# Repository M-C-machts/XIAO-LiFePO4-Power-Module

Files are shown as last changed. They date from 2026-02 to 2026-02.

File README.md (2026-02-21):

# XIAO LiFePO4 Module (Charging + 3.3V Regulator)

Small power-management PCB for running an ESP32 (or other 3.3V devices) from a single **LiFePO4** cell.

This board provides:
- **LiFePO4 charging** from ~5V input
- Proper handling of **charge + discharge**
- A **stable 3.3V output**
- **Battery voltage sense** output via a resistor divider (for ADC monitoring)

## Form factor / compatibility

This module matches the **Seeed Studio XIAO** form factor (approx. 21 x 17.5 mm) and is intended to be:
- soldered directly onto a **Seeed Studio XIAO ESP32C3** (castellated-module style), or
- used as a small **daughter board** on a larger PCB.

## Connections

- **Battery**: JST SH connector (LiFePO4 cell)
- **Charge input**: ~5V
- **Output**: regulated 3.3V
- **VBAT_SENSE**: divided battery-voltage output (connect to an ADC pin)

> Pin names / exact pinout depends on the PCB revision. See the schematic/PCB files in this repo.

## Typical use cases

- Battery-powered ESP32 sensor nodes
- Small portable projects using XIAO-sized MCUs
- Projects needing safe LiFePO4 charging + regulated 3.3V

## Notes / safety

- Use only **single-cell LiFePO4** batteries.
- Verify polarity before connecting the battery.
- Charging from ~5V assumes a suitable 5V source (USB, regulated supply, etc.).

## Repo contents

- KiCad project files (schematic + PCB)
- Manufacturing outputs - todo
- BOM / assembly notes - todo

## License

todo

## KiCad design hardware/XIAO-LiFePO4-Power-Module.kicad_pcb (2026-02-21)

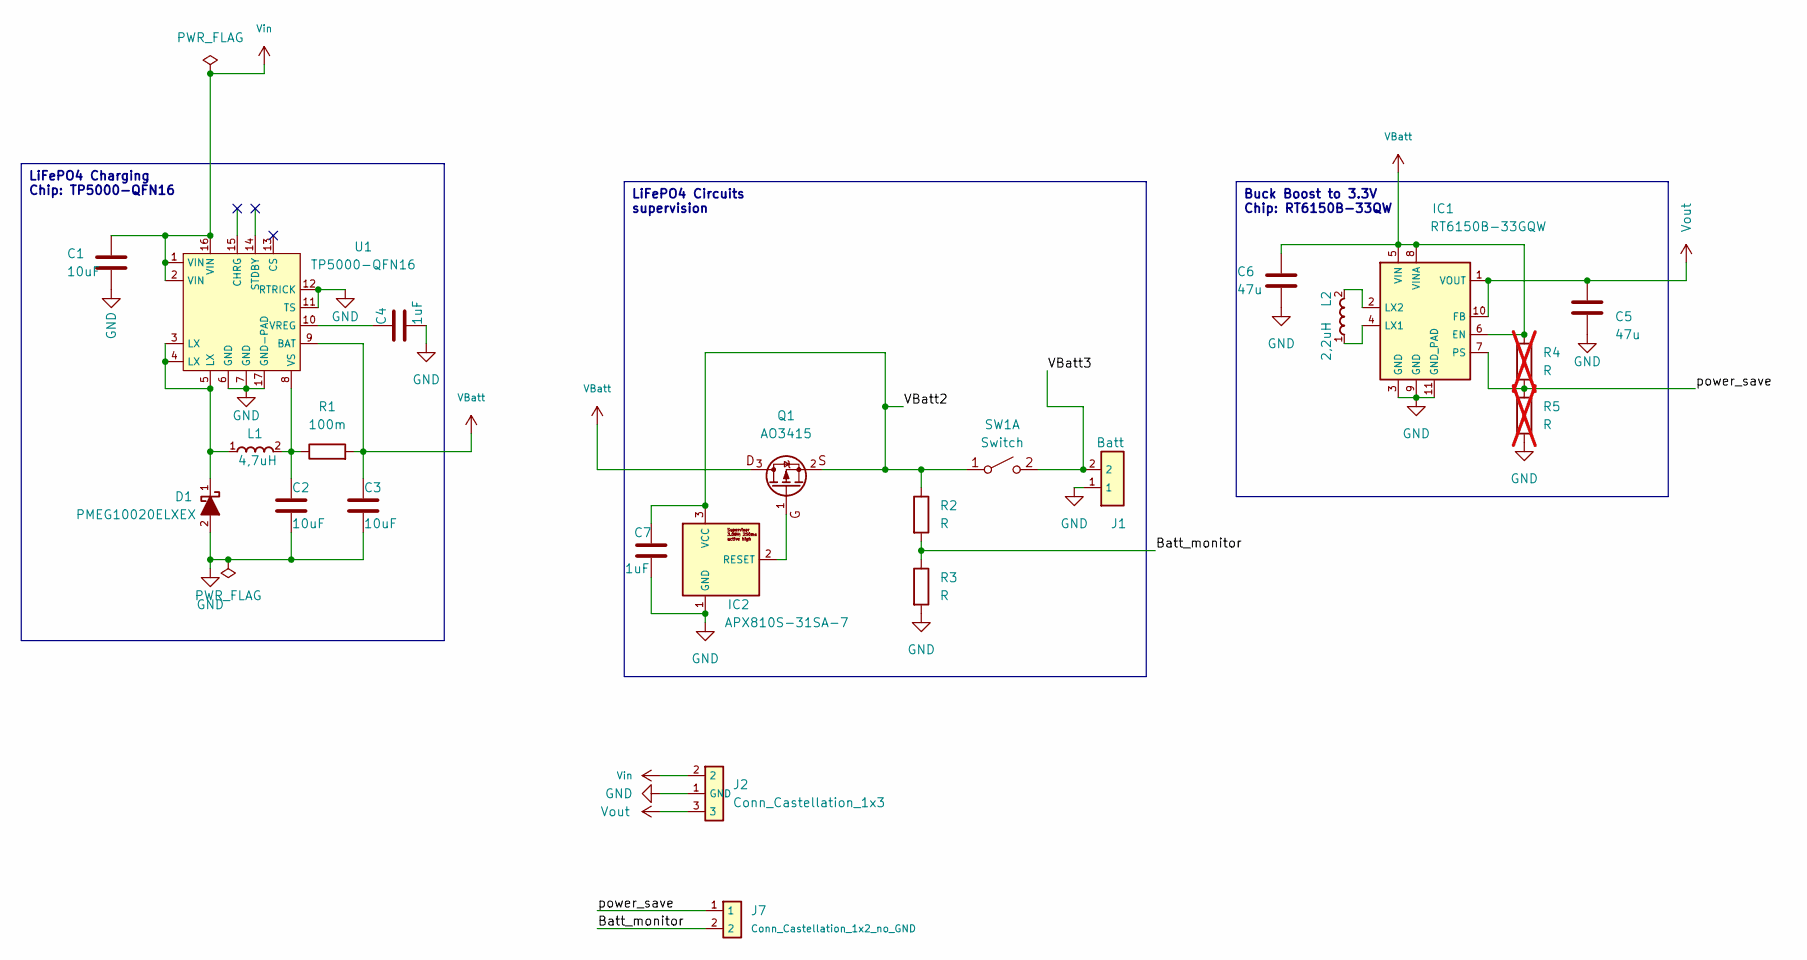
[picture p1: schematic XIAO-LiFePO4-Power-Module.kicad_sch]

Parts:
C1, C2, C3: 10uF; C_0805_2012Metric
C4, C7: 1uF; C_0603_1608Metric
C5, C6: 47u; C_0805_2012Metric
D1: PMEG10020ELXEX; PMEG4010EXEX; Mouser Part Number 771-PMEG10020ELXEX
IC1: RT6150B-33GQW; SON50P250X250X80-11N-D; Mouser Part Number 835-RT6150B-33GQW
IC2: APX810S-31SA-7; SOT-23-3_Marcus; Manufacturer_Part_Number APX810S-31SA-7
J1: Conn_JST-XH_1x2; Mouser Part Number 306-B2B-XH-AMLFSNP
J2: Conn_Castellation_1x3; Conn_Castellated_1x3_GND_moved
J7: Conn_Castellation_1x2_no_GND; Conn_Castellated_1x2_no_GND
L1: 4,7uH; INDC3225X120N
L2: 2,2uH; INDC3225X120N
Q1: AO3415; SOT-23-3_Marcus; Manufacturer_Part_Number AO3415
R1: 100m; R_1206_3216Metric
R2, R3: R; R_0603_1608Metric
R4, R5: R; R_0603_1608Metric; not fitted
SW1: Switch; Conn_Mechc.-solder-pad_1x2
U1: TP5000-QFN16

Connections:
/Batt_monitor: J7.2, R2.2, R3.1
/VBatt2: C7.1, IC2.3 (VCC), Q1.2 (S), R2.1, SW1.1 (A)
/VBatt3: J1.2, SW1.2 (B)
/power_save: IC1.7 (PS), J7.1, R4.2, R5.1
GND: C1.2, C2.2, C3.2, C4.2, C5.2, C6.2, C7.2, D1.2, IC1.3 (GND), IC1.9 (GND), IC1.11 (GND_PAD), IC2.1 (GND), J1.1, J2.1 (GND), R3.2, R5.2, U1.6 (GND), U1.7 (GND), U1.11 (TS), U1.12 (RTRICK), U1.17 (GND-PAD)
unnamed: D1.1, L1.1, U1.3 (LX), U1.4 (LX), U1.5 (LX)
unnamed: IC1.4 (LX1), L2.1
unnamed: IC1.2 (LX2), L2.2
unnamed: IC2.2 (RESET), Q1.1 (G)
unnamed: C4.1, U1.10 (VREG)
unnamed: C2.1, L1.2, R1.1, U1.8 (VS)
VBatt: C3.1, C6.1, IC1.5 (VIN), IC1.6 (EN), IC1.8 (VINA), Q1.3 (D), R1.2, R4.1, U1.9 (BAT)
Vin: C1.1, J2.2, U1.1 (VIN), U1.2 (VIN), U1.16 (VIN)
Vout: C5.1, IC1.1 (VOUT), IC1.10 (FB), J2.3

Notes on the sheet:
Buck Boost to 3.3V Chip: RT6150B-33QW
LiFePO4 Circuits supervision
LiFePO4 Charging Chip: TP5000-QFN16

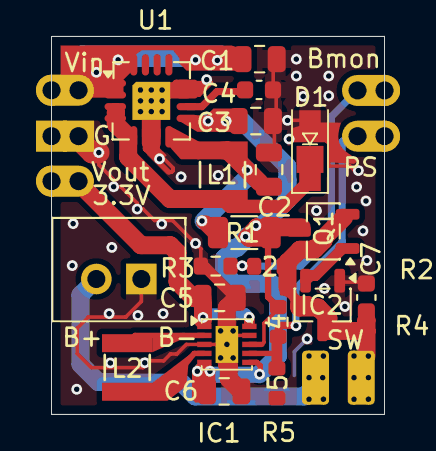
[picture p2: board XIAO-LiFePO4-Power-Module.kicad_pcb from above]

Board: 2 copper layers, 18.5 x 21.0 mm, 23 parts (0 on the bottom side), 14 nets.

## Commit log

2026-02-04 Add new project
    [LiFePO4-charge-discharge-board.kicad_pcb, LiFePO4-charge-discharge-board.kicad_sch]
2026-02-05 Add Working charge section
    [LiFePO4-charge-discharge-board.kicad_pcb]
2026-02-08 rewire circuit
    [LiFePO4-charge-discharge-board.kicad_pcb, LiFePO4-charge-discharge-board.kicad_sch]
2026-02-19 Finish version V1.0
    [LiFePO4-charge-discharge-board.kicad_pcb, LiFePO4-charge-discharge-board.kicad_sch]
2026-02-21 Reorganize repo
    [XIAO-LiFePO4-Power-Module.kicad_pcb, XIAO-LiFePO4-Power-Module.kicad_sch]
